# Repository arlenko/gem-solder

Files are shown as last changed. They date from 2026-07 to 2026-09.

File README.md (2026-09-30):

# 💎 Gem Solder

## Overview

Gem Solder is an STM32-powered soldering iron controller for general-purpose C245 tips.
It runs from a PD-compatible USB-C power source or from a DC power source of up to 24V,
including 3S–6S battery packs. USB-C power delivery negotiates up to 20V.

The user interface features a 128×32 OLED display and two buttons. An RGB
status LED gives visual feedback on the current operating mode.

The firmware is a fork of [IronOS](https://github.com/Ralim/IronOS). It ships with the IronOS feature set including a UI available in 35 languages.

The firmware measures the heater resistance of the fitted tip to compute how much power it can handle — up to 140W from DC and up to 100W over USB-C.
The delivered power therefore stays accurate across tips from different manufacturers.

Handle connector built into the 3D-printed housing. The housing carries the connector body, and a
matching PCB piece drops into it, so the pins and wires are soldered to that piece instead of a
special-purpose handle connector having to be sourced.

**Check out the [releases page](https://github.com/arlenko/gem-solder/releases)!**

The ZIP file shipped with a release contains everything needed to build, including a
[bill of materials](BOM/Gem%20Solder%20BOM.xlsx) for sourcing components and cost estimation,
an [interactive BOM](BOM/ibom.html) for convenient PCB assembly by hand, compiled
[bootloader](https://github.com/arlenko/IronOS-dfu) and firmware binaries, and STL files for
3D printing the enclosure.

**Get help and share your ideas on the [discussions](https://github.com/arlenko/gem-solder/discussions) page!**

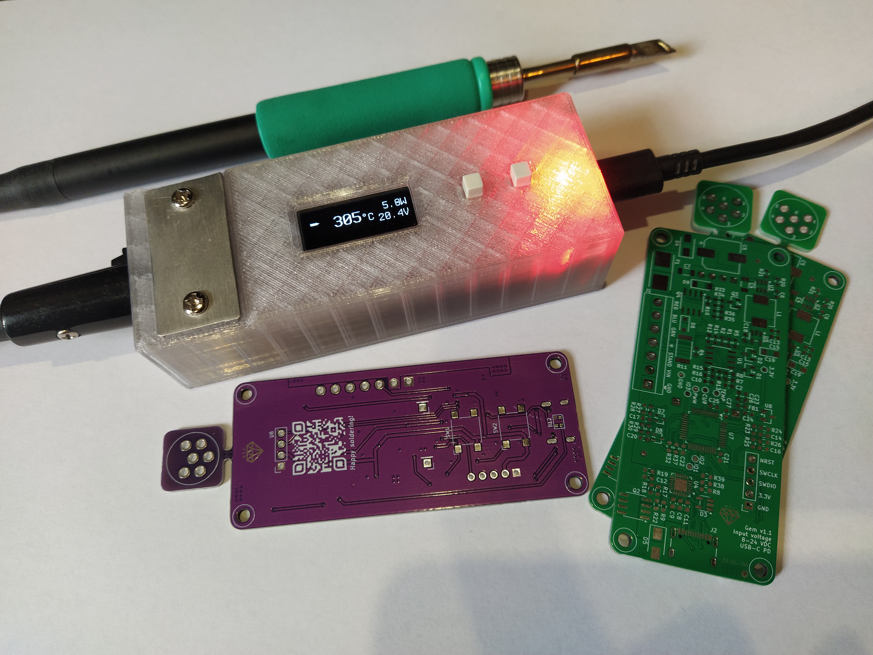
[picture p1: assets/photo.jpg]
Gem Solder


## Table of contents

- [Overview](#overview)
- [Features](#features)
- [Schematic](#schematic)
- [Hardware](#hardware)
- [Enclosure](#enclosure)
- [Firmware flashing](#firmware-flashing)
- [User interface](#user-interface)
- [Power supply recommendations](#power-supply-recommendations)
- [License](#license)

## Features

- Compact, DIY-friendly, two-layer 80×34 mm PCB.
- Current sensing feature measures the heater element's resistance to derive an
  accurate power estimate, so the iron works correctly with aftermarket tips whose resistance differs
  from the 2.4Ω of a genuine C245 tip.
- Resting the metal ring of the handle on a metal plate pulls the stand-sense input
  low and drops the iron to the sleep temperature, slowing tip oxidation. A quick
  tap on the plate toggles sleep when _Tap to sleep_ is enabled in the settings menu.
- An adjustable timeout setting returns the iron to the home screen and
  lets the tip cool down if it stays in sleep mode for too long.
- RGB status LED colour by mode:
  - 🟩 green - standby
  - 🟥 red pulse - heating
  - 🟥 red static - at setpoint
  - 🟦 cyan pulse - cooling, still hot
  - 🟪 violet - sleeping
- Once the DFU bootloader has been flashed to the device, all later firmware
  updates can be done over a USB data cable.
- PID temperature control, adjustable power limit, power pulse to keep power banks
  awake and more from IronOS.
- PD debug menu to read the power source capabilities.
- USB-C PD and an XT60 connector make it workable from a power bank or battery pack, for soldering away from the workbench.
- 20 kHz heater PWM keeps the switching noise of the high-current drive above the audible range.

## Schematic

Gem Solder schematic

## Hardware

Gem Solder PCB was designed in [KiCad](https://www.kicad.org/). It's a two-layer board
with a breakaway panel for a handle connector.

The heart of the device is the STM32F103C8T6 — an ARM Cortex-M3 MCU with 20 KB RAM and
64 KB flash. The STUSB4500QTR is a standalone PD sink controller, responsible for PD
negotiation and VBUS management. It communicates with the MCU via I²C.

The AD8629ARZ is a high-precision, zero-drift operational amplifier that amplifies the
microvolt-level signal from the tip thermocouple.

The tip heater power stage consists of a P-channel MOSFET and a discrete push-pull driver
with a zener diode for maintaining the gate voltage at a safe operating level.

The AP63300WU-7 buck converter provides 4.6 V for biasing the WS2812 RGB LED, then a 3.3 V LDO
regulator steps that down to supply the MCU, the OLED, the op-amp, and the
ambient temperature sensor.

A 5 mΩ current sense resistor enables current measurement for accurate PWM duty
calculation and tip presence detection.

Here's a photo of the assembled and bare PCBs:
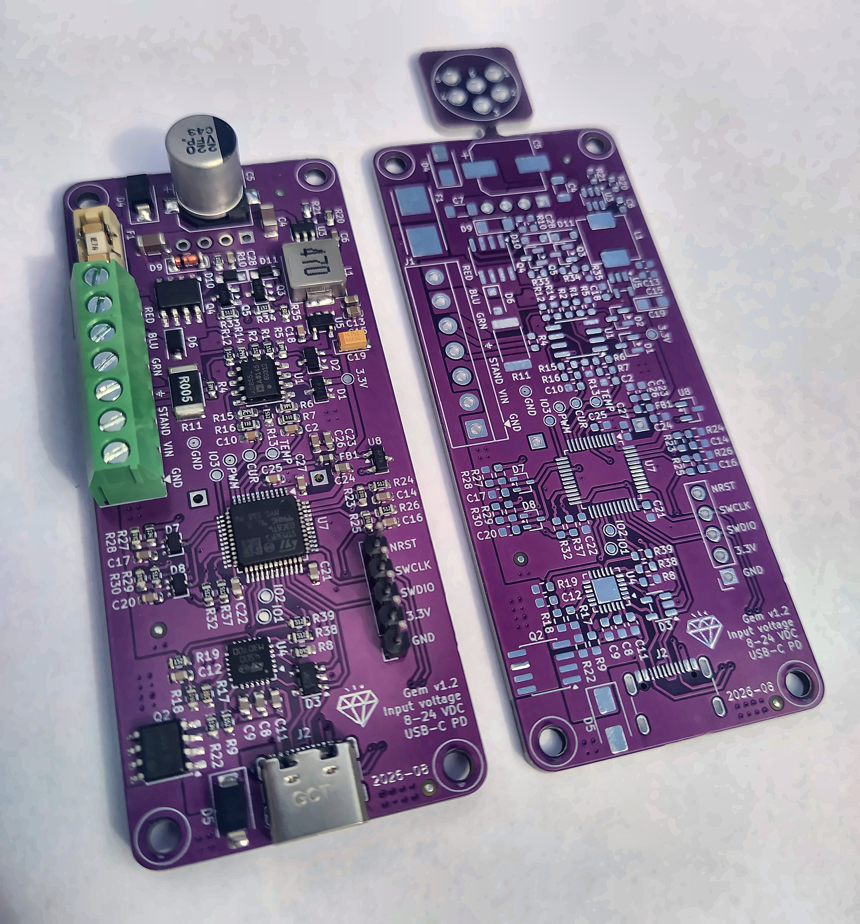
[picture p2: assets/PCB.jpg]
PCB


## Enclosure

Print the enclosure in a semi-transparent material to keep the status LED visible.

The 3D-printed enclosure has a built-in handle connector. Insert the connector PCB piece and
plug in the handle before soldering the pins and wires.

The image below shows how the connector needs to be wired to the screw terminal:

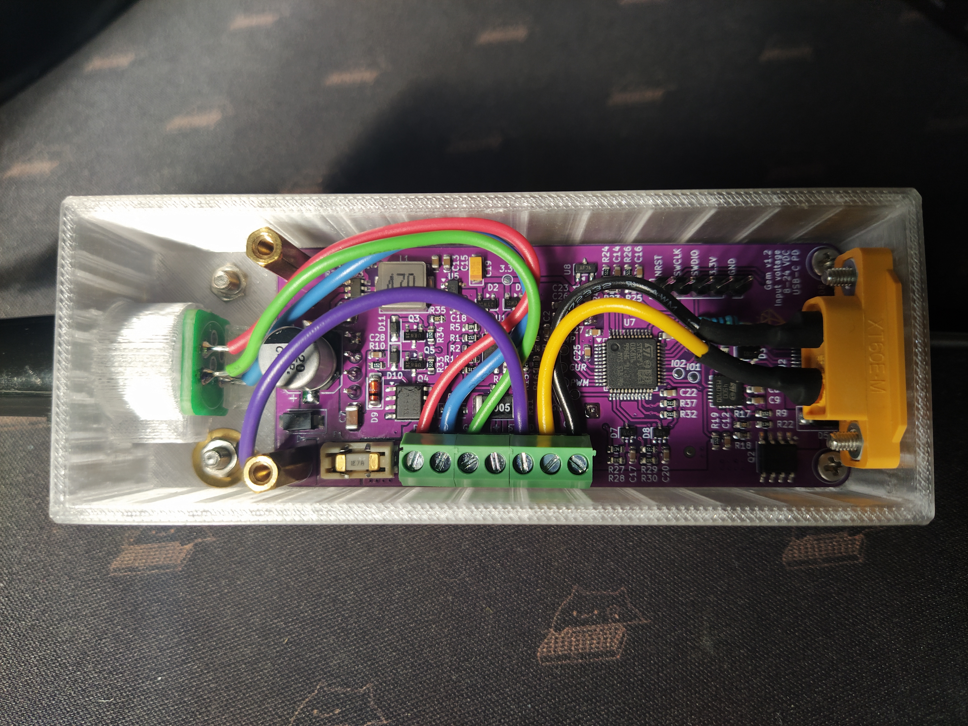
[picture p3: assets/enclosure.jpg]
Enclosure


## Firmware flashing

The STM32F103 has no built-in USB bootloader, so the first flash needs an SWD programmer such
as ST-LINK or DAPLink, wired to the 5-pin SWD header on the board.

Once the DFU bootloader has been flashed, all later updates run over a USB data cable using
[dfu-util](https://dfu-util.sourceforge.net/).

### Flashing via SWD

The flashing instructions depend on the tool and software being used. A genuine ST-LINK can
be used with STM32CubeIDE. DAPLink can be used with the OpenOCD CLI utility:

```sh
sudo openocd -f interface/cmsis-dap.cfg -c "adapter usb vid_pid 0x1a86 0x8012" \
          -f target/stm32f1x.cfg \
          -c "program Firmware/Gem_EN.hex verify reset exit"
```

### Flashing via USB

Once the DFU bootloader has been flashed to the device using SWD, firmware can be flashed
over a USB cable. To enter the DFU bootloader, click and hold button A and connect the USB
cable. The IronOS splash logo should appear on the display, followed by a message reading
"DFU bootloader". Then use dfu-util to upload the firmware:

```sh
sudo dfu-util -a 0 -D Firmware/Gem_EN.dfu -R
```

## User interface

Two buttons control the device:

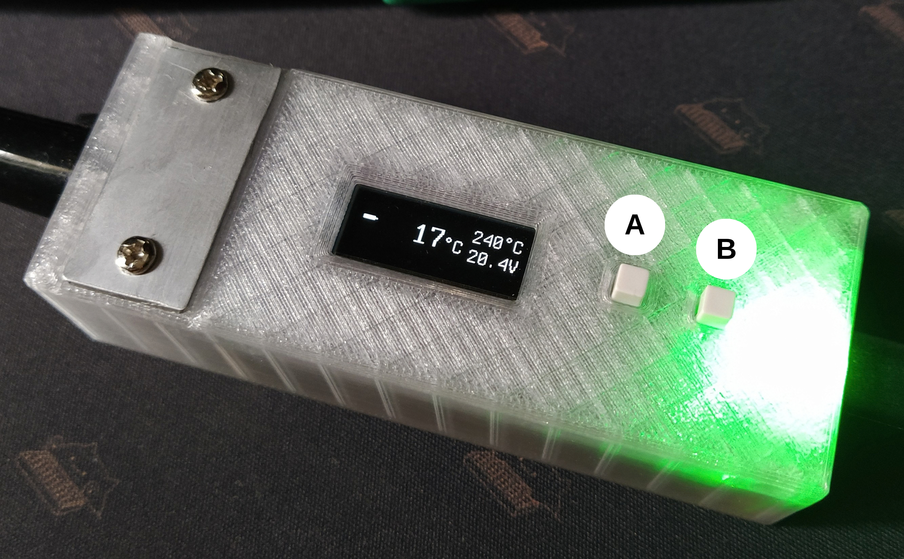
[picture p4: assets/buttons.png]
Buttons


Their functions are as follows:

- **On device power-up:** click and hold button A to enter the DFU bootloader if that was
  flashed to the device. Click and hold button B to enter factory bootloader mode.
- **On the home screen:** click button A to enter soldering mode. Click button B to enter
  device settings. Click and hold button A to adjust the set temperature. Click and hold
  button B to enter the debug menu.
- **In the settings menu:** use button B to scroll and button A to select.
- **In the debug menu:** use button A to scroll and button B to exit. Click and hold button B
  while in the debug menu to enter the PD debug menu.
- **In soldering mode:** click either button to adjust the temperature. Click and hold button B
  to exit to the home screen.

## Power supply recommendations

If an SMPS DC power supply is chosen as a power source, a **SELV power supply with a floating
output is required**. Do not use power supply units whose DC output is connected to mains earth.
Due to how the C245 tips are internally constructed, they provide a low-impedance path between
the RED terminal, to which positive voltage is applied, and the GREEN terminal, which is
connected to mains earth. While the Gem Solder's high-impedance path between the tip body and
the earth terminal should not cause a short circuit, PELV power supplies are not recommended
anyway.

⚠️ **Do not connect USB-C and DC power sources simultaneously!** USB and DC power paths are
internally joined on the board, so one power source ends up connected straight to another.

## License

Gem Solder PCB and enclosure designs are licensed under [CERN Open Hardware Licence Version 2](LICENSE-CERN-OHL-S).
Firmware code is covered by the [GNU General Public License v3.0](LICENSE-GPL-3.0) license unless noted elsewhere.

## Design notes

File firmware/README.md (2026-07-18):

# Gem Firmware
This firmware is derived from [IronOS](https://github.com/Ralim/IronOS)
(v2.23 commit [543fcd0](https://github.com/Ralim/IronOS/commit/543fcd0be6f28daac2f69c1caa4cce1047e1be24)),
originally targeting the Miniware TS101. Due to significant hardware differences between the TS101 and Gem maintaining a separate copy became necessary. Upstream IronOS changes are not automatically merged; this fork is maintained independently.

## Hardware

- **MCU**: STM32F103C8T6 (Cortex-M3, 64K flash, 20K RAM)
- **Display**: 128x32 OLED. SSD1306 display driver
- **Power**: DC and USB-C PD. STUSB4500 PD controller

## Building

1. Enter the source directory:
```
cd source
```

2. Create a Python virtual environment:
```
python -m venv ironos-venv
```

3. Activate virtual environment:
```
source ./ironos-venv/bin/activate # or activate.fish for the fish shell
```

4. Install dependencies:
```
pip install bdflib pyyaml
```

5. Build the firmware:
```
make -j$(nproc)
```
If you need SWD enabled for debugging:
```
make -j$(nproc) swd_enable=1
```

For all subsequent builds in a new terminal session consider activating a Python virtual environment before building the firmware.

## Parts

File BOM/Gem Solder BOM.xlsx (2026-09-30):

Reference | Qty | Value | Footprint | Description | LCSC Part Number | MPN | Link | Price per single unit | Price per Qty
C2,C10,C18 | 3 | 1n | Capacitor_SMD:C_0603_1608Metric | Unpolarized capacitor, small symbol | C163508 | C0603C102J3GACAUTO | C163508 (https://www.lcsc.com/product-detail/) | $0.0127 | $0.0381
C4,C7 | 2 | 10u | Capacitor_SMD:C_1206_3216Metric | Unpolarized capacitor, small symbol | C105175 | MSASU31LBB5106KTNA01 | C105175 (https://www.lcsc.com/product-detail/) | $0.4207 | $0.8414
C5 | 1 | 220u | Capacitor_SMD:CP_Elec_8x10.5 | Polarized capacitor | C278406 | EEEFP1V221AP | C278406 (https://www.lcsc.com/product-detail/) | $0.4923 | $0.4923
C6,C12,C14,C16,C17,C20,C25,C26,C27,C28 | 10 | 100n | Capacitor_SMD:C_0603_1608Metric | Unpolarized capacitor, small symbol | C346190 | CL10B104KA8WPNC | C346190 (https://www.lcsc.com/product-detail/) | $0.0278 | $0.2780
C8,C9,C11,C21,C22,C23,C24 | 7 | 1u | Capacitor_SMD:C_0603_1608Metric | Unpolarized capacitor, small symbol | C85862 | GCM188R71E105KA64D | C85862 (https://www.lcsc.com/product-detail/) | $0.0893 | $0.6251
C13,C15 | 2 | 22u | Capacitor_SMD:C_0603_1608Metric | Unpolarized capacitor, small symbol | C2762594 | CL10A226MO7JZNC | C2762594 (https://www.lcsc.com/product-detail/) | $0.1292 | $0.2584
C19 | 1 | 4.7u 10V | Capacitor_Tantalum_SMD:CP_EIA-3216-18_Kemet-A | Polarized capacitor, small symbol | C7187 | TAJA475K016RNJ | C7187 (https://www.lcsc.com/product-detail/) | $0.2206 | $0.2206
D1,D2 | 2 | BAV199.215 | Package_TO_SOT_SMD:SOT-23 | BAV99 High-speed switching diodes, SOT-23 | C40919 | BAV199.215 | C40919 (https://www.lcsc.com/product-detail/) | $0.0660 | $0.1320
D3 | 1 | ESDA6V1SC5 | Package_TO_SOT_SMD:SOT-23-5 | Quad TVS Diode Array, 6.1V Standoff, 4 Channels, 400W, ±30kV, SOT-23-5 | C2935146 | ESDA6V1SC5 | C2935146 (https://www.lcsc.com/product-detail/) | $0.2890 | $0.2890
D4,D5 | 2 | SMAJ24CA | Diode_SMD:D_SMA |  | C148223 | SMAJ24CA | C148223 (https://www.lcsc.com/product-detail/) | $0.1069 | $0.2138
D6 | 1 | PMEG6010CEH.115 | Diode_SMD:D_SOD-123F | Schottky diode, small symbol | C53113897 | PMEG6010CEH.115-JSM | C53113897 (https://www.lcsc.com/product-detail/) | $0.0469 | $0.0469
D7,D8 | 2 | BAT54SW | Package_TO_SOT_SMD:SOT-323_SC-70 | Vr 30V, If 200mA, Dual schottky barrier diode, in series, SOT-323 | C78606 | BAT54SW.115 | C78606 (https://www.lcsc.com/product-detail/) | $0.0535 | $0.1070
D9 | 1 | BZV55-B12.115 | Diode_SMD:D_MiniMELF | Zener diode, small symbol | C426807 | BZV55-B12.115 | C426807 (https://www.lcsc.com/product-detail/) | $0.0979 | $0.0979
D10,D11 | 2 | 1N4148WSF-7 | Diode_SMD:D_SOD-323_HandSoldering |  | C119617 | 1N4148WSF-7 | C119617 (https://www.lcsc.com/product-detail/) | $0.6677 | $1.3354
D12 | 1 | WS2812B-2020 | Footprints:RGB_LED_WS2812B-2020_2.0x2.0mm |  | C52917434 | WS2812B-2020-V6 | C52917434 (https://www.lcsc.com/product-detail/) | $0.0916 | $0.0916
F1 | 1 | 7A | Footprints:0154100DR | Fuse | C206918 | 0154007.DR | C206918 (https://www.lcsc.com/product-detail/) | $1.9183 | $1.9183
FB1 | 1 | BLM18AG331SN1D | Inductor_SMD:L_0603_1608Metric | Ferrite bead, small symbol | C113010 | BLM18AG331SN1D | C113010 (https://www.lcsc.com/product-detail/) | $0.0139 | $0.0139
J2 | 1 | USB4105-GF-A-060 | Connector_USB:USB_C_Receptacle_GCT_USB4105-xx-A_16P_TopMnt_Horizontal | USB 2.0-only 16P Type-C Receptacle connector | C3025063 | USB4105-GF-A-060 | C3025063 (https://www.lcsc.com/product-detail/) | $1.1952 | $1.1952
J3,J4 | 2 | Conn_01x01_Pin | Connector_PinHeader_2.54mm:PinHeader_1x01_P2.54mm_Vertical | Generic connector, single row, 01x01, script generated | C7501259 | ZX-PZ2.54-1-1PZZ | C7501259 (https://www.lcsc.com/product-detail/) | $0.0146 | $0.0292
J5 | 1 | Conn_01x05_Socket | Connector_PinSocket_2.54mm:PinSocket_1x05_P2.54mm_Vertical | Generic connector, single row, 01x05, script generated | C7171947 | 215298-5 | C7171947 (https://www.lcsc.com/product-detail/) | $0.8446 | $0.8446
L1 | 1 | 47uH | Inductor_SMD:L_APV_APH0630 | Inductor | C706600 | SMMS0630-470MT | C706600 (https://www.lcsc.com/product-detail/) | $0.1268 | $0.1268
Q2,Q4 | 2 | AOSP21321 | Package_SO:SOIC-8_3.9x4.9mm_P1.27mm | -6.7A Id, -20V Vds, P-Channel HEXFET Power MOSFET, SO-8 | C560863 | AOSP21321 | C560863 (https://www.lcsc.com/product-detail/) | $0.2159 | $0.4318
Q3,Q5 | 2 | BSR14 | Package_TO_SOT_SMD:SOT-23 | TRANS NPN 40V 800mA SOT-23 | C258201 | BSR14 | C258201 (https://www.lcsc.com/product-detail/) | $0.2776 | $0.5552
R1,R2,R9,R10,R19,R31,R34 | 7 | 1.5k | Resistor_SMD:R_0603_1608Metric | Resistor, small symbol | C2930050 | FRC0603F1501TS | C2930050 (https://www.lcsc.com/product-detail/) | $0.0027 | $0.0189
R4 | 1 | 1M | Resistor_SMD:R_0603_1608Metric | Resistor, small symbol | C2907003 | FRC0603F1004TS | C2907003 (https://www.lcsc.com/product-detail/) | $0.0027 | $0.0027
R5,R6 | 2 | 390k | Resistor_SMD:R_0603_1608Metric | Resistor, small symbol | C2907158 | FRC0603J394 TS | C2907158 (https://www.lcsc.com/product-detail/) | $0.0022 | $0.0044
R7,R16 | 2 | 10R | Resistor_SMD:R_0603_1608Metric | Resistor, small symbol | C2907091 | FRC0603J100 TS | C2907091 (https://www.lcsc.com/product-detail/) | $0.0027 | $0.0054
R8,R28,R30 | 3 | 10k | Resistor_SMD:R_0603_1608Metric | Resistor, small symbol | C4134045 | RCS060310K0JNEA | C4134045 (https://www.lcsc.com/product-detail/) | $0.0476 | $0.1428
R17,R20,R35 | 3 | 20k | Resistor_SMD:R_0603_1608Metric | Resistor, small symbol | C2907011 | FRC0603F2002TS | C2907011 (https://www.lcsc.com/product-detail/) | $0.0027 | $0.0081
R11 | 1 | RMF2512FTR005 | Resistor_SMD:R_2512_6332Metric | Resistor, small symbol | C48533600 | FRM253WJR005TM | C48533600 (https://www.lcsc.com/product-detail/) | $0.0335 | $0.0335
R12,R13,R24,R26,R29,R32,R37,R38,R39 | 9 | 5k1 | Resistor_SMD:R_0603_1608Metric | Resistor, small symbol | C2907044 | FRC0603F5101TS | C2907044 (https://www.lcsc.com/product-detail/) | $0.0028 | $0.0252
R14,R15 | 2 | 240k | Resistor_SMD:R_0603_1608Metric | Resistor, small symbol | C2930036 | FRC0603J244TS | C2930036 (https://www.lcsc.com/product-detail/) | $0.0023 | $0.0046
R18,R23,R25 | 3 | 100R | Resistor_SMD:R_0603_1608Metric | Resistor, small symbol | C2076611 | CRCW0603100RJNEAC | C2076611 (https://www.lcsc.com/product-detail/) | $0.0156 | $0.0468
R20,R22,R27 | 3 | 130k | Resistor_SMD:R_0603_1608Metric | Resistor, small symbol | C2907099 | FRC0603J134 TS | C2907099 (https://www.lcsc.com/product-detail/) | $0.0024 | $0.0072
R21 | 1 | 27k | Resistor_SMD:R_0603_1608Metric | Resistor, small symbol | C2930084 | FRC0603F2702TS | C2930084 (https://www.lcsc.com/product-detail/) | $0.0028 | $0.0028
SW1,SW2 | 2 | SW_Omron_B3FS | Button_Switch_SMD:SW_SPST_Omron_B3FS-100xP | Omron B3FS 6x6mm single pole normally-open tactile switch | C5594007 | B3FS-1050 | C5594007 (https://www.lcsc.com/product-detail/) | $1.2121 | $2.4242
U1 | 1 | AD8629ARZ | Package_SO:SOIC-8_3.9x4.9mm_P1.27mm | Dual Precision, Very Low Noise, Low Input Bias Current, Wide Bandwidth JFET Operational Amplifiers, SOIC-8 | C23487 | AD8629ARZ-REEL7 | C23487 (https://www.lcsc.com/product-detail/) | $4.9347 | $4.9347
U3 | 1 | AP63300WU-7 | Package_TO_SOT_SMD:TSOT-23-6 | 2A, 500kHz Buck DC/DC Converter, adjustable output voltage, TSOT-23-6 | C2158012 | AP63300WU-7 | C2158012 (https://www.lcsc.com/product-detail/) | $0.6580 | $0.6580
U4 | 1 | STUSB4500QTR | Footprints:QFN-24-1EP_4x4mm_P0.5mm_EP2.65x2.65mm | Stand-alone USB PD controller (with sink Auto-run mode), QFN-24 | C2678061 | STUSB4500QTR | C2678061 (https://www.lcsc.com/product-detail/) | $2.1956 | $2.1956
U5 | 1 | MIC5219-3.3YM5 | Package_TO_SOT_SMD:SOT-23-5 | 500mA low dropout linear regulator, fixed 3.3V output, SOT-23-5 | C29613 | MIC5219-3.3YM5-TR | C29613 (https://www.lcsc.com/product-detail/) | $0.5892 | $0.5892
U6 | 1 | OLED0.91_128x32_I2C | Footprints:OLED_128x32_0.91 | 0.91 128x32 SSD1306 chip I2C LCD, OLED, Graphic RoHS | C5248081 | HS91L02W2C01 | C5248081 (https://www.lcsc.com/product-detail/) | $2.2378 | $2.2378
U7 | 1 | STM32F103C8T6 | Package_QFP:LQFP-48_7x7mm_P0.5mm | STMicroelectronics Arm Cortex-M3 MCU, 64KB flash, 20KB RAM, 72 MHz, 2.0-3.6V, 37 GPIO, LQFP48 | C8734 | STM32F103C8T6 | C8734 (https://www.lcsc.com/product-detail/) | $2.0073 | $2.0073
U8 | 1 | MCP9700AT-ETT | Package_TO_SOT_SMD:SOT-23 | Low power, analog thermistor temperature sensor, ±2C accuracy, -40C to +125C, in SOT-23-3 | C127949 | MCP9700AT-E/TT | C127949 (https://www.lcsc.com/product-detail/) | $0.4460 | $0.4460
 |  |  |  |  |  |  |  | Total for PCB components | $25.9777
PCB | 1 |  |  |  |  |  |  | $2.0000 | $2.0000
Stencil | 1 |  |  |  |  |  |  | $7.0000 | $7.0000
 |  |  |  |  |  |  |  | Total for PCB fabrication | $9.00
XT60E-M connector | 1 |  |  |  | C3040679 | XT60E-M.G.Y | C3040679 (https://www.lcsc.com/product-detail/) | $0.6084 | $0.6084
Screw terminal (2 pin) | 2 | DEGSON DG350-3.5-02P-14-00A(H) |  |  | C2760668 |  | C2760668 (https://www.lcsc.com/product-detail/) | $0.1706 | $0.3412
Screw terminal (3 pin) | 1 | DEGSON DG350-3.5-03P-14-00A(H) |  |  | C2760669 |  | C2760669 (https://www.lcsc.com/product-detail/) | $0.1899 | $0.1899
Handle connector pins | 5 |  |  |  | C17283940 | 1460-9-00-80-00-00-03-0 | C17283940 (https://www.lcsc.com/product-detail/) | $0.3633 | $1.8165
Screws M2.5x6 | 4 |  |  | For sequring PCB and XT60 connector
Screws M2.5x10 | 4 |  |  | For sequring enclosure lid and standby sense plate
Nuts M2.5 | 2 |  |  | For sequring standby sense plate
PCB standoffs L=16 | 2 |  |  | For sequring PCB and enclosure lid
Threaded inserts for plastic M2.5 | 4
Ring terminal M2.5 | 1 |  |  | For connecting standby sense wire to sense plate
Button cups | 2 | B32-1060 |  |  | C2733560 | B32-1060 | C2733560 (https://www.lcsc.com/product-detail/) | $0.1032 | $0.2064
Enclosure 3D print | 1 |  |  |  |  |  |  | $5.0000 | $5.0000
 |  |  |  |  |  |  |  | Total for others | $8.16
T245 handle | 1 |  |  |  |  |  |  | $15.0000 | $15.0000
C245 tip | 1 |  |  |  |  |  |  | $5.0000 | $5.0000
 |  |  |  |  |  |  |  | Total for handle+tip | $20.00
 |  |  |  |  |  |  |  | Total | $63.14

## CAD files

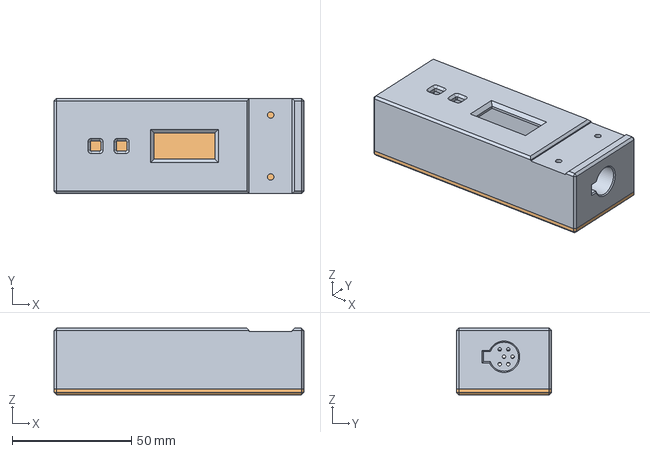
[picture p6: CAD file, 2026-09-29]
enclosure/Gem_Solder_Enclosure.FCStd
105.0 x 40.0 x 28.0 mm
Тіло
Enclosure_Lid

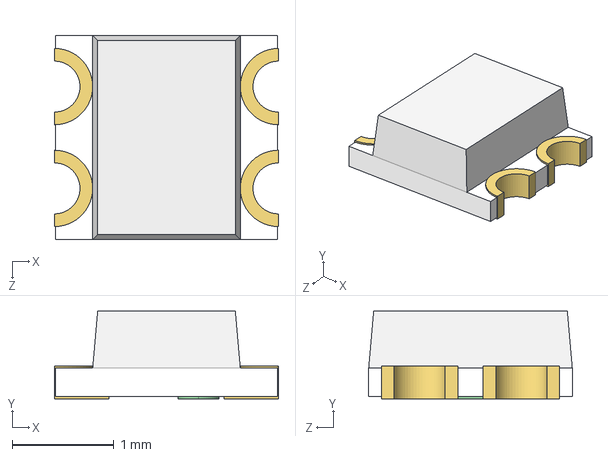
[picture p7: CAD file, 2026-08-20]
hardware/3D-models/WS2812-2020.STEP
2.20 x 0.86 x 2.00 mm

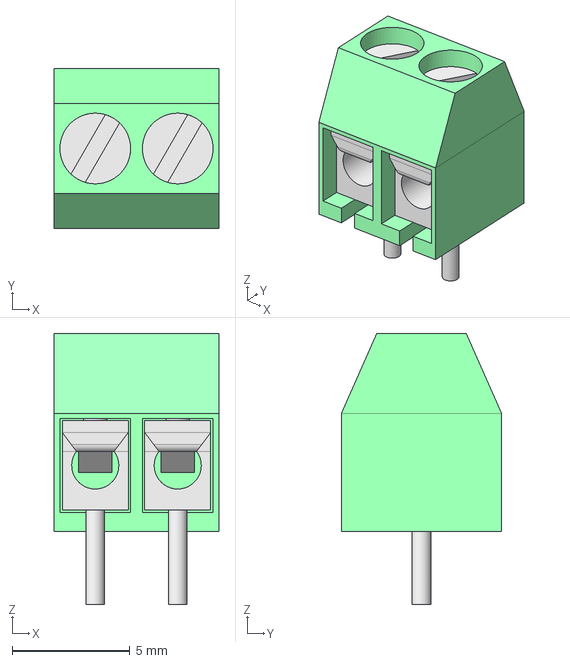
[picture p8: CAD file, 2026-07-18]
hardware/3D-models/DG350-3.5-2P.step
7.00 x 6.80 x 11.5 mm

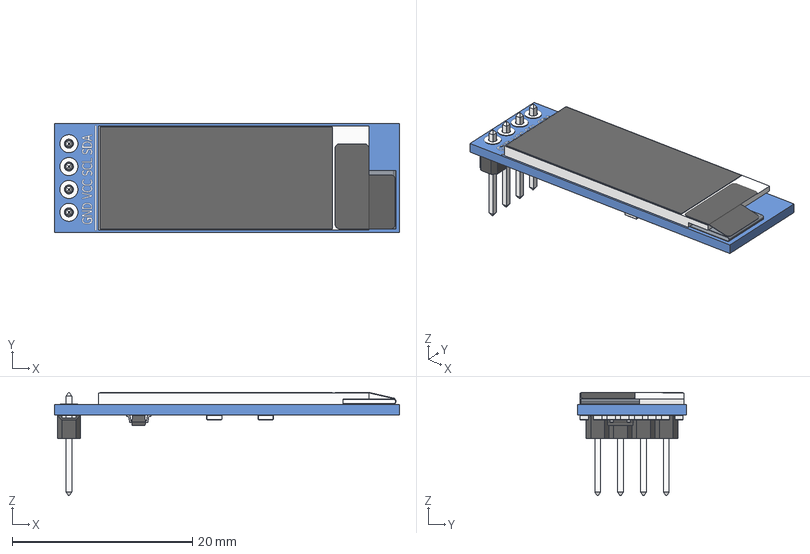
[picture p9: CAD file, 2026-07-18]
hardware/3D-models/OLED_0.91_128x32.stp
38.3 x 12.1 x 11.5 mm
OLED_0.91_128x32
Pin Header 4 x 1 TH 2.54mm Pitch
RESC-0603 x 13
2SD0601A

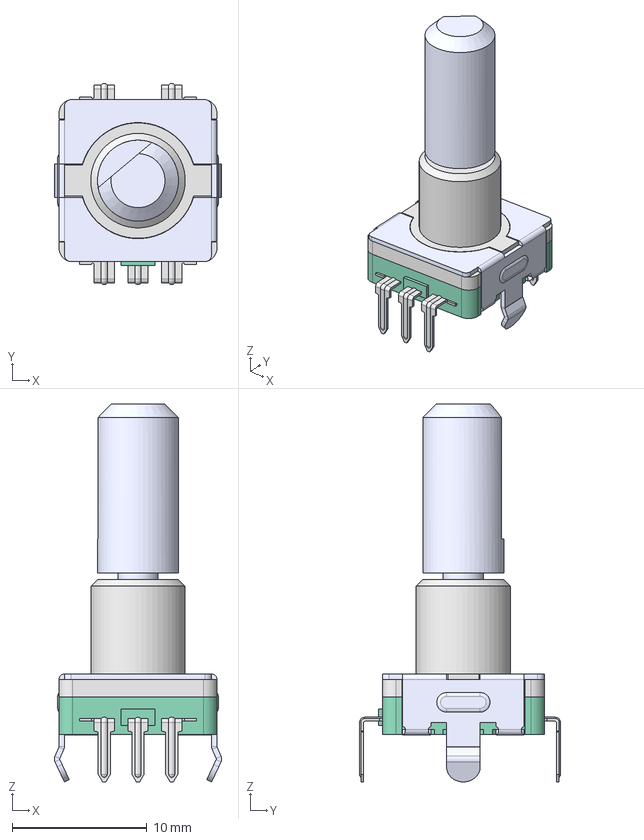
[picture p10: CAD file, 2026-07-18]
hardware/3D-models/EC11-THT-20F-green.step
12.4 x 14.9 x 28.0 mm
Lb7
20F
EC11-Housing-THT

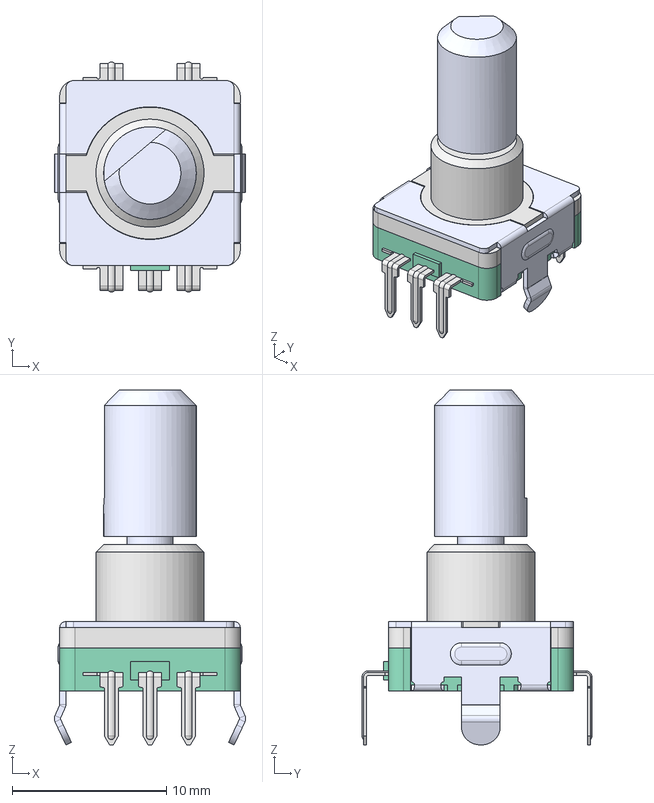
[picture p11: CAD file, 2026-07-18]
hardware/3D-models/EC11-THT-15F-green.step
12.4 x 14.9 x 23.0 mm
Lb5
15F
EC11-Housing-THT

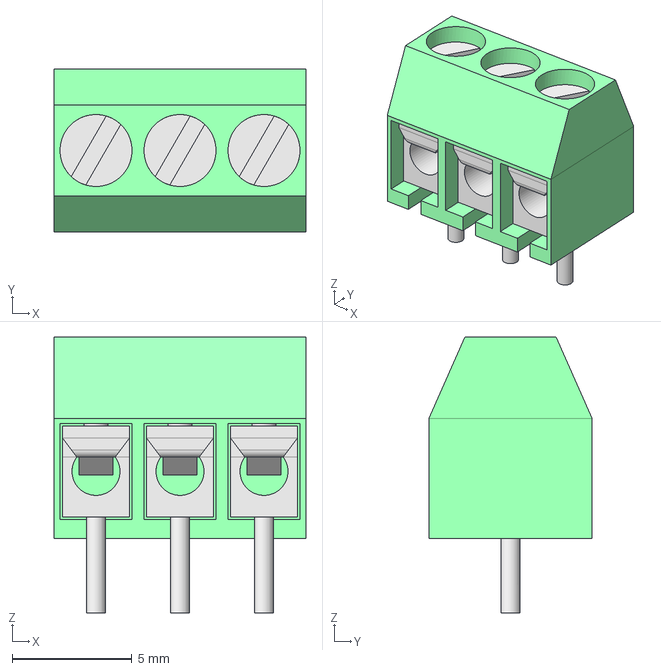
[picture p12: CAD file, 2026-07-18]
hardware/3D-models/DG350-3.5-3P.step
10.5 x 6.80 x 11.5 mm

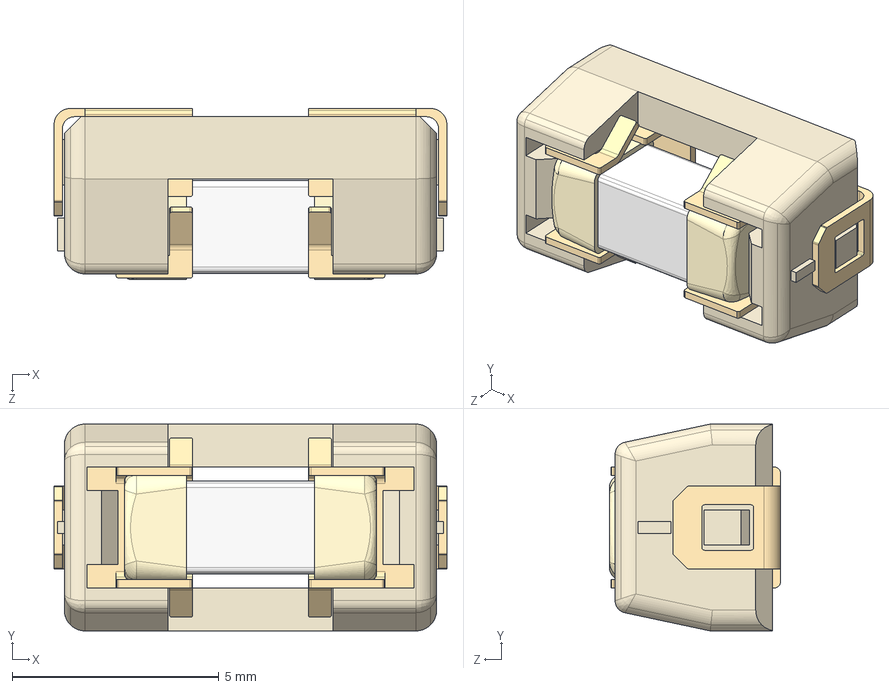
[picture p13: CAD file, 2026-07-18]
hardware/3D-models/0154007.DRTL.stp
9.50 x 5.00 x 4.14 mm
0679H1000-xxsingle fonts v2.step
Plastic holder-0.step
Terminal.step

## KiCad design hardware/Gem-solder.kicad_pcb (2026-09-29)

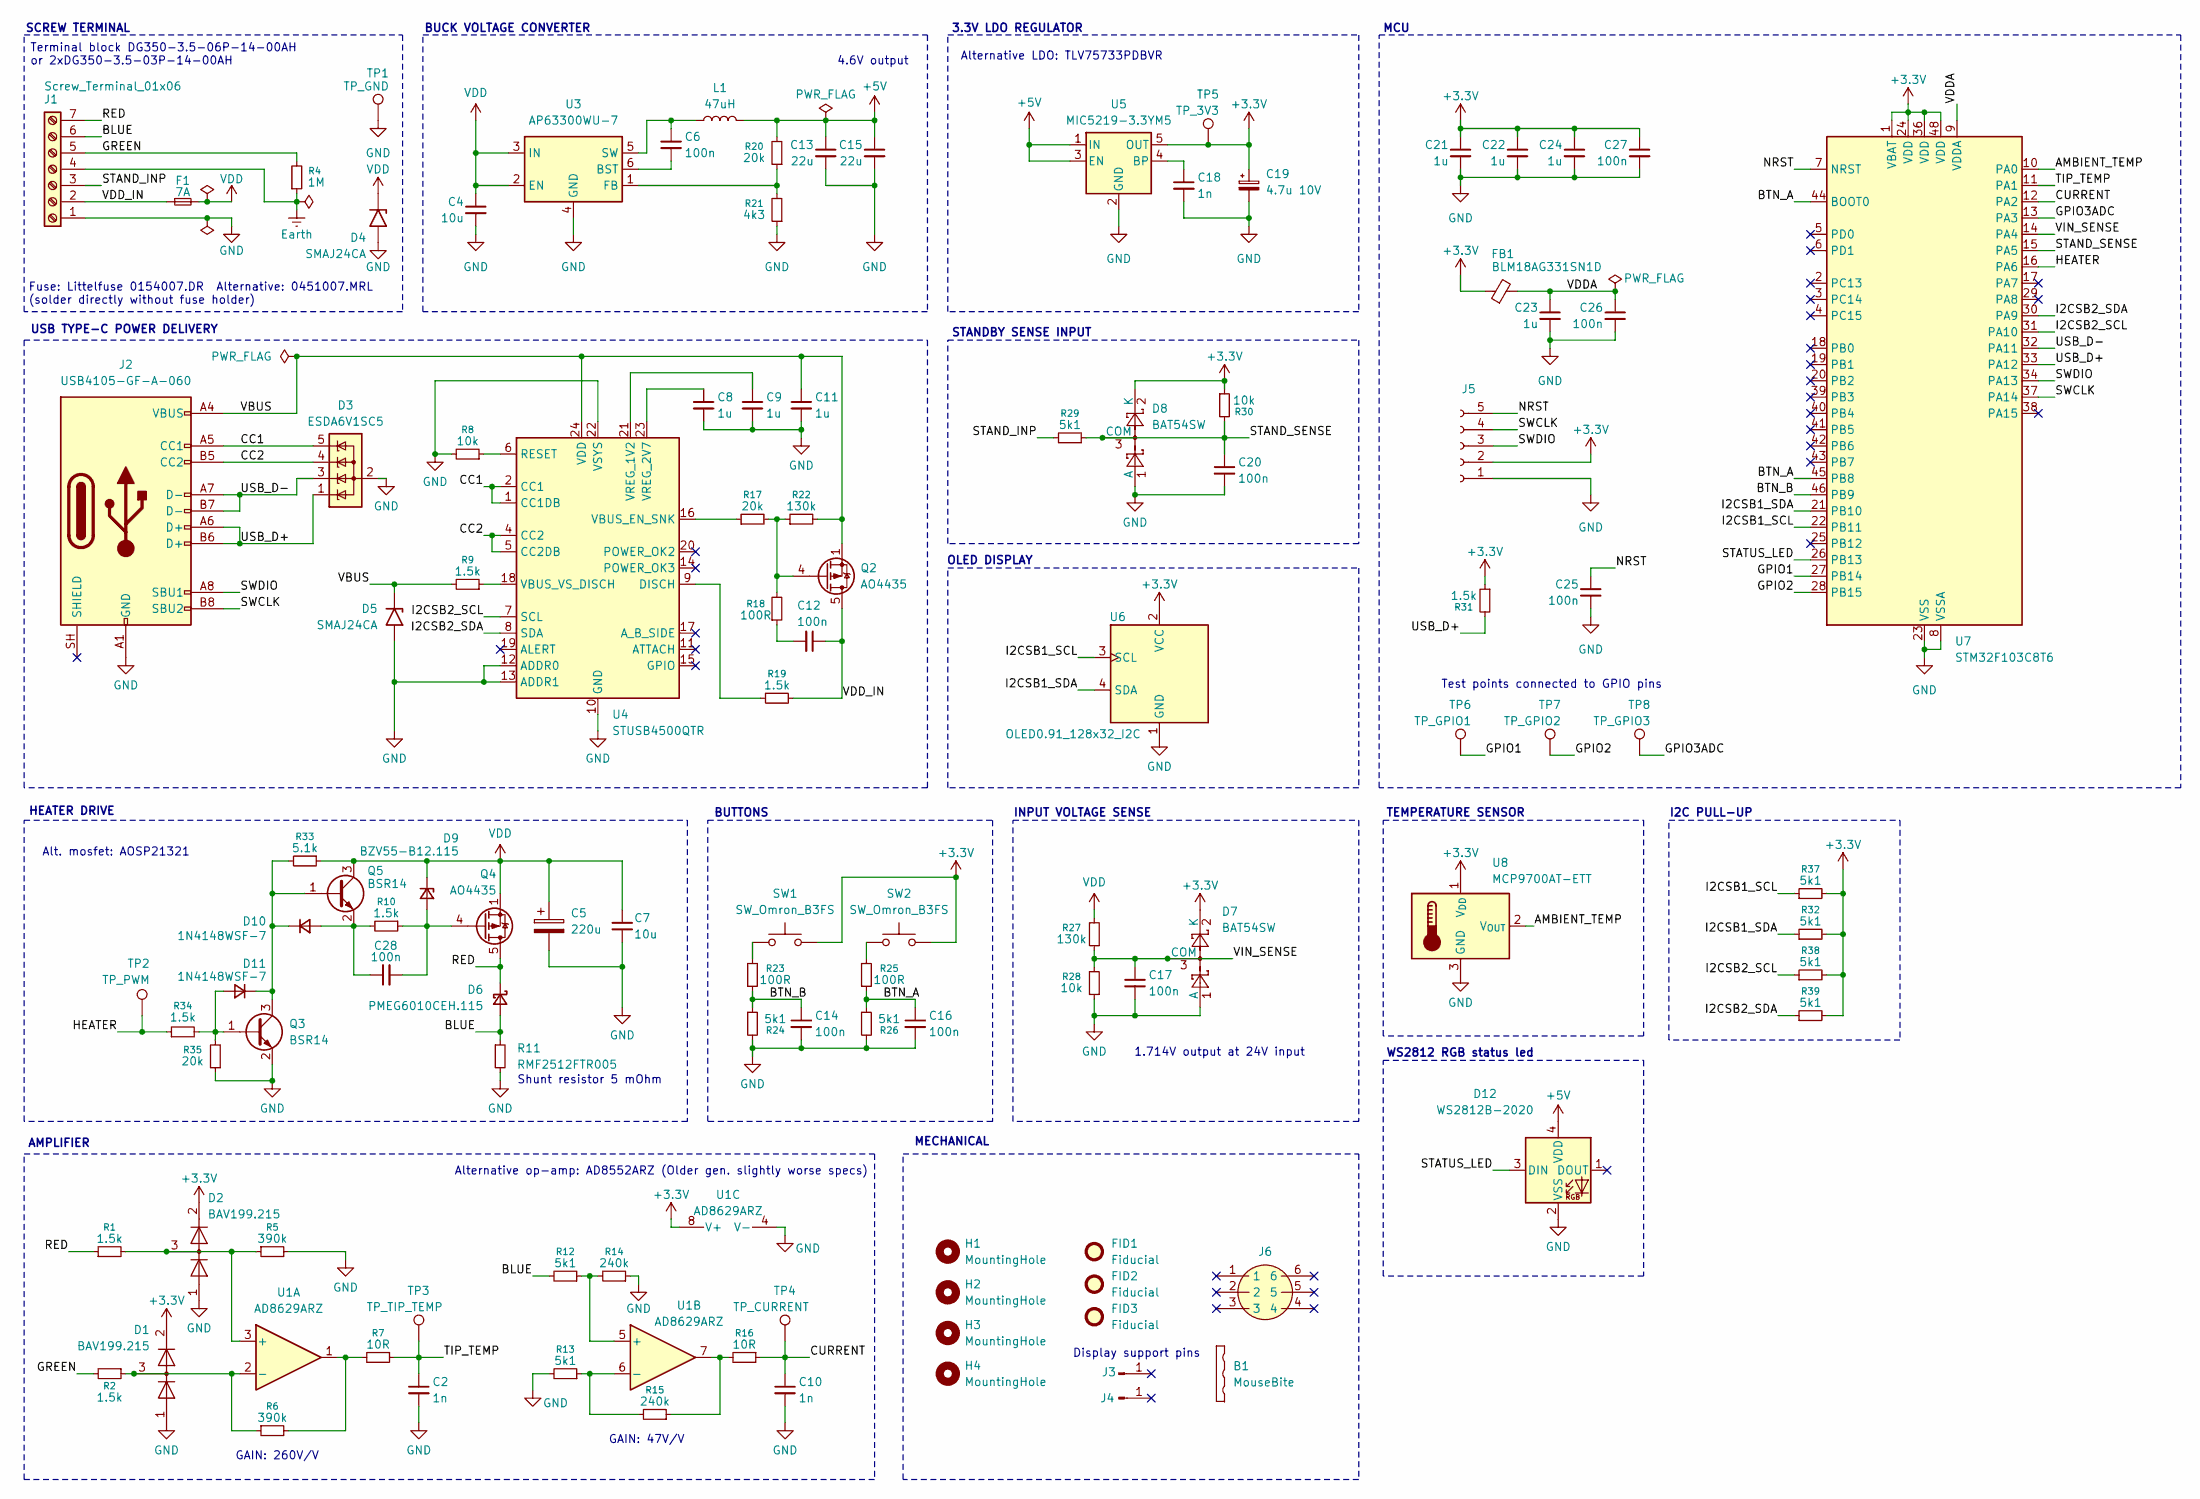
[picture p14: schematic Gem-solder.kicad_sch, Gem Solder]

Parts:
B1: MouseBite; MouseBite-Slot_2.0x2.0mm_outset_D0.5mm_P0.85mm_3h
C2, C10, C18: 1n; C_0603_1608Metric; MPN C0603C102J3GACAUTO; LCSC Part Number C163508
C4, C7: 10u; C_1206_3216Metric; MPN MSASU31LBB5106KTNA01; LCSC Part Number C105175
C5: 220u; CP_Elec_8x10.5; MPN EEEFP1V221AP; LCSC Part Number C278406
C6, C12, C14, C16, C17, C20, C25, C26, C27, C28: 100n; C_0603_1608Metric; MPN CL10B104KA8WPNC; LCSC Part Number C346190
C8, C9, C11, C21, C22, C23, C24: 1u; C_0603_1608Metric; MPN GCM188R71E105KA64D; LCSC Part Number C85862
C13, C15: 22u; C_0603_1608Metric; MPN CL10A226MO7JZNC; LCSC Part Number C2762594
C19: 4.7u 10V; CP_EIA-3216-18_Kemet-A; MPN TAJA475K016RNJ; LCSC Part Number C7187
D1, D2: BAV199.215; SOT-23; MPN BAV199.215; LCSC Part Number C40919
D3: ESDA6V1SC5; SOT-23-5; MPN ESDA6V1SC5; LCSC Part Number C2935146
D4, D5: SMAJ24CA; D_SMA; MPN SMAJ24CA; LCSC Part Number C148223
D6: PMEG6010CEH.115; D_SOD-123F; MPN PMEG6010CEH.115-JSM; LCSC Part Number C53113897
D7, D8: BAT54SW; SOT-323_SC-70; MPN BAT54SW.115; LCSC Part Number C78606
D9: BZV55-B12.115; D_MiniMELF; MPN BZV55-B12.115; LCSC Part Number C426807
D10, D11: 1N4148WSF-7; D_SOD-323_HandSoldering; MPN 1N4148WSF-7; LCSC Part Number C119617
D12: WS2812B-2020; RGB_LED_WS2812B-2020_2.0x2.0mm; MPN WS2812B-2020-V6; LCSC Part Number C52917434
F1: 7A; 0154100DR; MPN 0154007.DR; LCSC Part Number C206918
FB1: BLM18AG331SN1D; L_0603_1608Metric; MPN BLM18AG331SN1D; LCSC Part Number C113010
FID1, FID2, FID3: Fiducial; Fiducial_0.75mm_Mask1.5mm
H1, H2, H3, H4: MountingHole; MountingHole_2.7mm_M2.5_DIN965
J1: Screw_Terminal_01x06; TerminalBlock_DG350-3.5-07P-14-00AH_1x07_P3.50mm
J2: USB4105-GF-A-060; USB_C_Receptacle_GCT_USB4105-xx-A_16P_TopMnt_Horizontal; MPN USB4105-GF-A-060; LCSC Part Number C3025063
J3, J4: Conn_01x01_Pin; PinHeader_1x01_P2.54mm_Vertical; MPN ZX-PZ2.54-1-1PZZ; LCSC Part Number C7501259
J5: Conn_01x05_Socket; PinSocket_1x05_P2.54mm_Vertical; MPN 215298-5; LCSC Part Number C7171947
J6: Connector_Hirose_RPC1-12RB-6P(72)
L1: 47uH; L_APV_APH0630; MPN SMMS0630-470MT; LCSC Part Number C706600
Q2, Q4: AO4435; SOIC-8_3.9x4.9mm_P1.27mm; MPN IRF7416TRPBF; LCSC Part Number C3000
Q3, Q5: BSR14; SOT-23; MPN BSR14; LCSC Part Number C258201
R1, R2, R9, R10, R19, R31, R34: 1.5k; R_0603_1608Metric; MPN FRC0603F1501TS; LCSC Part Number C2930050
R4: 1M; R_0603_1608Metric; MPN FRC0603F1004TS; LCSC Part Number C2907003
R5, R6: 390k; R_0603_1608Metric; MPN FRC0603J394 TS; LCSC Part Number C2907158
R7, R16: 10R; R_0603_1608Metric; MPN FRC0603J100 TS; LCSC Part Number C2907091
R8, R28, R30: 10k; R_0603_1608Metric; MPN RCS060310K0JNEA; LCSC Part Number C4134045
R11: RMF2512FTR005; R_2512_6332Metric; MPN FRM253WJR005TM; LCSC Part Number C48533600
R12, R13, R24, R26, R29, R32, R37, R38, R39: 5k1; R_0603_1608Metric; MPN FRC0603F5101TS; LCSC Part Number C2907044
R14, R15: 240k; R_0603_1608Metric; MPN FRC0603J244TS; LCSC Part Number C2930036
R17, R20, R35: 20k; R_0603_1608Metric; MPN FRC0603F2002TS; LCSC Part Number C2907011
R18, R23, R25: 100R; R_0603_1608Metric; MPN CRCW0603100RJNEAC; LCSC Part Number C2076611
R21: 4k3; R_0603_1608Metric; MPN RS-03K4301FT; LCSC Part Number C310281
R22, R27: 130k; R_0603_1608Metric; MPN FRC0603J134 TS; LCSC Part Number C2907099
R33: 5.1k; R_0603_1608Metric; MPN FRC0603F1501TS; LCSC Part Number C2930050
SW1, SW2: SW_Omron_B3FS; SW_SPST_Omron_B3FS-100xP; MPN B3FS-1050; LCSC Part Number C5594007
TP1: TP_GND; TestPoint_Pad_D1.0mm
TP2: TP_PWM; TestPoint_Pad_D1.0mm
TP3: TP_TIP_TEMP; TestPoint_Pad_D1.0mm
TP4: TP_CURRENT; TestPoint_Pad_D1.0mm
TP5: TP_3V3; TestPoint_Pad_D1.0mm
TP6: TP_GPIO1; TestPoint_Pad_D1.0mm
TP7: TP_GPIO2; TestPoint_Pad_D1.0mm
TP8: TP_GPIO3; TestPoint_Pad_D1.0mm
U1: AD8629ARZ; SOIC-8_3.9x4.9mm_P1.27mm; MPN AD8629ARZ-REEL7; LCSC Part Number C23487
U3: AP63300WU-7; TSOT-23-6; MPN AP63300WU-7; LCSC Part Number C2158012
U4: STUSB4500QTR; QFN-24-1EP_4x4mm_P0.5mm_EP2.65x2.65mm; MPN STUSB4500QTR; LCSC Part Number C2678061
U5: MIC5219-3.3YM5; SOT-23-5; MPN MIC5219-3.3YM5-TR; LCSC Part Number C29613
U6: OLED0.91_128x32_I2C; OLED_128x32_0.91; MPN HS91L02W2C01; LCSC Part Number C5248081
U7: STM32F103C8T6; LQFP-48_7x7mm_P0.5mm; MPN STM32F103C8T6; LCSC Part Number C8734
U8: MCP9700AT-ETT; SOT-23; MPN MCP9700AT-E/TT; LCSC Part Number C127949

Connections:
+3.3V: C19.1, C21.1, C22.1, C24.1, C27.1, D1.2 (A), D2.2 (A), D7.2 (K), D8.2 (K), FB1.1, J5.2, R30.1, R31.1, R32.2, R37.2, R38.2, R39.2, SW1.2, SW2.2, TP5.1 (1_1), U1.8 (V+), U5.5 (OUT), U6.2 (VCC), U7.1 (VBAT), U7.24 (VDD), U7.36 (VDD), U7.48 (VDD), U8.1 (V_{DD})
+5V: C13.1, C15.1, D12.4 (VDD), L1.2, R20.2, U5.1 (IN), U5.3 (EN)
/AMBIENT_TEMP: U7.10 (PA0), U8.2 (V_{OUT})
/BLUE: D6.2 (A), J1.6, R11.1, R12.2
/BTN_A: C16.1, R25.1, R26.1, U7.44 (BOOT0), U7.45 (PB8)
/BTN_B: C14.1, R23.1, R24.1, U7.46 (PB9)
/CC1: D3.5 (K), J2.A5 (CC1), U4.1 (CC1DB), U4.2 (CC1)
/CC2: D3.4 (K), J2.B5 (CC2), U4.4 (CC2), U4.5 (CC2DB)
/CURRENT: C10.1, R16.1, TP4.1 (1_1), U7.12 (PA2)
/GPIO1: TP6.1 (1_1), U7.27 (PB14)
/GPIO2: TP7.1 (1_1), U7.28 (PB15)
/GPIO3ADC: TP8.1 (1_1), U7.13 (PA3)
/GREEN: J1.5, R2.2, R4.2
/HEATER: R34.1, TP2.1 (1_1), U7.16 (PA6)
/I2CSB1_SCL: R37.1, U6.3 (SCL), U7.22 (PB11)
/I2CSB1_SDA: R32.1, U6.4 (SDA), U7.21 (PB10)
/I2CSB2_SCL: R38.1, U4.7 (SCL), U7.31 (PA10)
/I2CSB2_SDA: R39.1, U4.8 (SDA), U7.30 (PA9)
/NRST: C25.1, J5.5, U7.7 (NRST)
/RED: D6.1 (K), J1.7, Q4.5 (D), Q4.6 (D), Q4.7 (D), Q4.8 (D), R1.1
/STAND_INP: J1.3, R29.2
/STAND_SENSE: C20.1, D8.3 (COM), R29.1, R30.2, U7.15 (PA5)
/STATUS_LED: D12.3 (DIN), U7.26 (PB13)
/SWCLK: J2.B8 (SBU2), J5.4, U7.37 (PA14)
/SWDIO: J2.A8 (SBU1), J5.3, U7.34 (PA13)
/TIP_TEMP: C2.1, R7.1, TP3.1 (1_1), U7.11 (PA1)
/USB_D+: D3.1 (K), J2.A6 (D+), J2.B6 (D+), R31.2, U7.33 (PA12)
/USB_D-: D3.3 (K), J2.A7 (D-), J2.B7 (D-), U7.32 (PA11)
/VBUS: C11.1, D5.1 (A1), J2.A4 (VBUS), J2.A9 (VBUS), J2.B4 (VBUS), J2.B9 (VBUS), Q2.1 (S), Q2.2 (S), Q2.3 (S), R9.2, R22.2, U4.24 (VDD)
/VDDA: C23.1, C26.1, FB1.2, U7.9 (VDDA)
/VDD_IN: C12.1, F1.1, J1.2, Q2.5 (D), Q2.6 (D), Q2.7 (D), Q2.8 (D), R19.2
/VIN_SENSE: C17.1, D7.3 (COM), R27.1, R28.2, U7.14 (PA4)
Earth: J1.4, R4.1
GND: C2.2, C4.2, C5.2, C7.2, C8.2, C9.2, C10.2, C11.2, C13.2, C14.2, C15.2, C16.2, C17.2, C18.2, C19.2, C20.2, C21.2, C22.2, C23.2, C24.2, C25.2, C26.2, C27.2, D1.1 (K), D2.1 (K), D3.2 (A), D4.2 (A2), D5.2 (A2), D7.1 (A), D8.1 (A), D12.2 (VSS), J1.1, J2.A1 (GND), J2.A12 (GND), J2.B1 (GND), J2.B12 (GND), J5.1, Q3.2 (E), R5.2, R8.2, R11.2, R13.2, R14.1, R21.1, R24.2, R26.2, R28.1, R35.1, TP1.1 (1_1), U1.4 (V-), U3.4 (GND), U4.10 (GND), U4.12 (ADDR0), U4.13 (ADDR1), U4.22 (VSYS), U4.25 (GND), U5.2 (GND), U6.1 (GND), U7.8 (VSSA), U7.23 (VSS), U7.35 (VSS), U7.47 (VSS), U8.3 (GND)
unnamed: C12.2, R18.1
unnamed: C28.2, D9.2 (A), Q4.4 (G), R10.1
unnamed: C28.1, D10.2 (A), Q5.2 (E), R10.2
unnamed: D10.1 (K), D11.1 (K), Q3.3 (C), Q5.1 (B), R33.2
unnamed: D11.2 (A), Q3.1 (B), R34.2, R35.2
unnamed: Q2.4 (G), R17.2, R18.2, R22.1
unnamed: R6.2, R7.2, U1.1
unnamed: R15.1, R16.2, U1.7
unnamed: R23.2, SW1.1
unnamed: R25.2, SW2.1
unnamed: D2.3 (K), R1.2, R5.1, U1.3 (+)
unnamed: D1.3 (K), R2.1, R6.1, U1.2 (-)
unnamed: R12.1, R14.2, U1.5 (+)
unnamed: R13.1, R15.2, U1.6 (-)
unnamed: C6.2, U3.6 (BST)
unnamed: R20.1, R21.2, U3.1 (FB)
unnamed: C6.1, L1.1, U3.5 (SW)
unnamed: R19.1, U4.9 (DISCH)
unnamed: R8.1, U4.6 (RESET)
unnamed: R17.1, U4.16 (VBUS_EN_SNK)
unnamed: R9.1, U4.18 (VBUS_VS_DISCH)
unnamed: C9.1, U4.21 (VREG_1V2)
unnamed: C8.1, U4.23 (VREG_2V7)
unnamed: C18.1, U5.4 (BP)
VDD: C4.1, C5.1, C7.1, D4.1 (A1), D9.1 (K), F1.2, Q4.1 (S), Q4.2 (S), Q4.3 (S), Q5.3 (C), R27.2, R33.1, U3.2 (EN), U3.3 (IN)

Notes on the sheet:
3.3V LDO REGULATOR
MECHANICAL
Test points connected to GPIO pins
INPUT VOLTAGE SENSE
1.714V output at 24V input
Terminal block DG350-3.5-06P-14-00AH or 2xDG350-3.5-03P-14-00AH
HEATER DRIVE
BUTTONS
STANDBY SENSE INPUT
4.6V output
AMPLIFIER
OLED DISPLAY
TEMPERATURE SENSOR
Shunt resistor 5 mOhm
Fuse: Littelfuse 0154007.DR Alternative: 0451007.MRL (solder directly without fuse holder)
GAIN: 47V/V
Display support pins
SCREW TERMINAL
BUCK VOLTAGE CONVERTER
GAIN: 260V/V
Alternative op-amp: AD8552ARZ (Older gen. slightly worse specs)
Alt. mosfet: AOSP21321
I2C PULL-UP
MCU
Alternative LDO: TLV75733PDBVR
USB TYPE-C POWER DELIVERY
WS2812 RGB status led

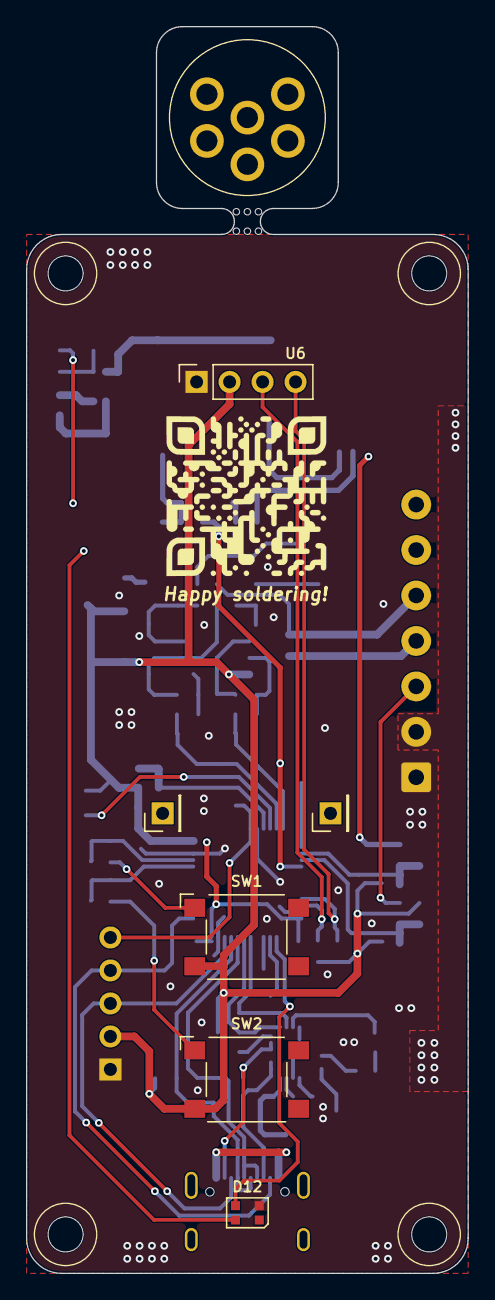
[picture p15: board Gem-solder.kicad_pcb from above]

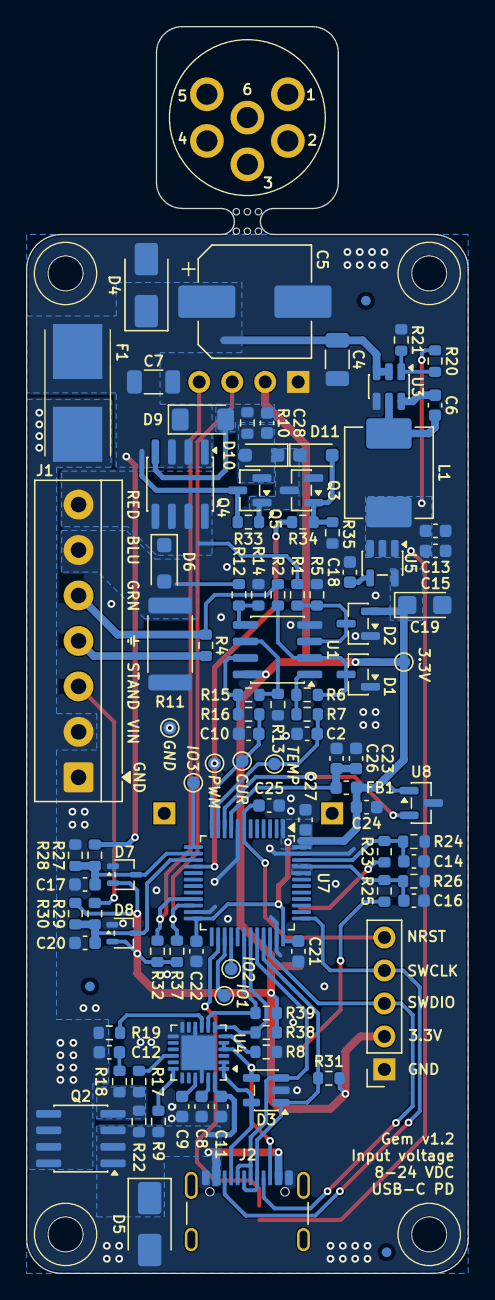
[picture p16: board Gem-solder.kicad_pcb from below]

Board: 2 copper layers, 34.0 x 96.0 mm, 113 parts (101 on the bottom side), 59 nets.

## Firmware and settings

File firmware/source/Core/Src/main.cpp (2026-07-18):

// By Ben V. Brown - V2.0 of the TS100 firmware

/*
 * Main.cpp bootstraps the device and then hands over to FreeRTOS and the threads
 */

#include "main.hpp"
#include "BSP.h"
#include "Settings.h"
#include "cmsis_os.h"
#include "power.hpp"
AccelType DetectedAccelerometerVersion = AccelType::None;
bool      settingsWereReset            = false;
// FreeRTOS variables

osThreadId          GUITaskHandle;
static const size_t GUITaskStackSize = 1024 / 2;
uint32_t            GUITaskBuffer[GUITaskStackSize];
osStaticThreadDef_t GUITaskControlBlock;

osThreadId          PIDTaskHandle;
static const size_t PIDTaskStackSize = 1024 / 2;
uint32_t            PIDTaskBuffer[PIDTaskStackSize];
osStaticThreadDef_t PIDTaskControlBlock;

// osThreadId          MOVTaskHandle;
// static const size_t MOVTaskStackSize = 1024 / 2;
// uint32_t            MOVTaskBuffer[MOVTaskStackSize];
// osStaticThreadDef_t MOVTaskControlBlock;

osThreadId          POWTaskHandle;
static const size_t POWTaskStackSize = 512 / 2;
uint32_t            POWTaskBuffer[POWTaskStackSize];
osStaticThreadDef_t POWTaskControlBlock;

// End FreeRTOS
// Main sets up the hardware then hands over to the FreeRTOS kernel
int main(void) {
  preRToSInit();

  resetWatchdog();
  // Testing for which accelerometer is mounted
  settingsWereReset = loadSettings(); // load the settings from flash

  setTipX10Watts(0); // force tip off

  resetWatchdog();
  /* Create the thread(s) */

  /* definition and creation of PIDTask - Heating control*/
  osThreadStaticDef(PIDTask, startPIDTask, osPriorityRealtime, 0, PIDTaskStackSize, PIDTaskBuffer, &PIDTaskControlBlock);
  PIDTaskHandle = osThreadCreate(osThread(PIDTask), NULL);

  /* definition and creation of POWTask - Power management for QC / PD */
  osThreadStaticDef(POWTask, startPOWTask, osPriorityAboveNormal, 0, POWTaskStackSize, POWTaskBuffer, &POWTaskControlBlock);
  POWTaskHandle = osThreadCreate(osThread(POWTask), NULL);

  // /* definition and creation of MOVTask - Accelerometer management */
  // osThreadStaticDef(MOVTask, startMOVTask, osPriorityNormal, 0, MOVTaskStackSize, MOVTaskBuffer, &MOVTaskControlBlock);
  // MOVTaskHandle = osThreadCreate(osThread(MOVTask), NULL);

  /* definition and creation of GUITask - The OLED control & update*/
  osThreadStaticDef(GUITask, startGUITask, osPriorityBelowNormal, 0, GUITaskStackSize, GUITaskBuffer, &GUITaskControlBlock);
  GUITaskHandle = osThreadCreate(osThread(GUITask), NULL);

  resetWatchdog();

  /* Start scheduler */
  osKernelStart();
  /* We should never get here as control is now taken by the scheduler */
  for (;;) {
  }
}

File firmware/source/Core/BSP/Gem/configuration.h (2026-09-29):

#ifndef CONFIGURATION_H_
#define CONFIGURATION_H_
#include <stdint.h>
/**
 * Configuration.h
 * Define here your default settings
 *
 */

//===========================================================================
//============================= Default Settings ============================
//===========================================================================
/**
 * Default soldering temp is 320.0 C
 * Temperature the iron sleeps at - default 150.0 C
 */

#define SLEEP_TEMP         150 // Default sleep temperature
#define BOOST_TEMP         420 // Default boost temp.
#define BOOST_MODE_ENABLED 1   // 0: Disable 1: Enable

/**
 * Blink the temperature on the cooling screen when its > 50C
 */
#define COOLING_TEMP_BLINK 0 // 0: Disable 1: Enable

/**
 * How many seconds/minutes we wait until going to sleep/shutdown.
 * Values -> SLEEP_TIME * 10; i.e. 5*10 = 50 Seconds!
 */
#define SLEEP_TIME    5  // x10 Seconds
#define SHUTDOWN_TIME 10 // Minutes

/**
 * Auto start off for safety.
 * Possible values are:
 *  0 - none
 *  1 - Soldering Temperature
 *  2 - Sleep Temperature
 *  3 - Sleep Off Temperature
 */
#define AUTO_START_MODE 0 // Default to none

/**
 * Locking Mode
 * When in soldering mode a long press on both keys toggle the lock of the buttons
 * Possible values are:
 *  0 - Desactivated
 *  1 - Lock except boost
 *  2 - Full lock
 */
#define LOCKING_MODE 0 // Default to desactivated for safety

/**
 * OLED Orientation
 *
 */
#define ORIENTATION_MODE     0 // 0: Right 1:Left 2:Automatic - Default Automatic
#define MAX_ORIENTATION_MODE 1 // Up to auto
// 0:Default 1:Reverse - Reverse the plus and minus button assigment for temperature change
#define REVERSE_BUTTON_TEMP_CHANGE 0

/**
 * OLED Brightness
 *
 */
//   #define MIN_BRIGHTNESS     1   // Min OLED brightness selectable
//   #define MAX_BRIGHTNESS     101 // Max OLED brightness selectable
#define MIN_BRIGHTNESS     0   // Min OLED brightness selectable
#define MAX_BRIGHTNESS     100 // Max OLED brightness selectable
#define BRIGHTNESS_STEP    25  // OLED brightness increment
#define DEFAULT_BRIGHTNESS 25  // default OLED brightness

/**
 * Temp change settings
 */
#define TEMP_CHANGE_SHORT_STEP     1  // Default temp change short step +1
#define TEMP_CHANGE_LONG_STEP      10 // Default temp change long step +10
#define TEMP_CHANGE_SHORT_STEP_MAX 50 // Temp change short step MAX value
#define TEMP_CHANGE_LONG_STEP_MAX  90 // Temp change long step MAX value

/* Power pulse for keeping power banks awake*/
#define POWER_PULSE_INCREMENT    1
#define POWER_PULSE_MAX          100 // x10 max watts
#define POWER_PULSE_WAIT_MAX     9   // 9*2.5s = 22.5 seconds
#define POWER_PULSE_DURATION_MAX 9   // 9*250ms = 2.25 seconds

#define POWER_PULSE_DEFAULT          0
#define POWER_PULSE_WAIT_DEFAULT     4 // Default rate of the power pulse: 4*2500 = 10000 ms = 10 s
#define POWER_PULSE_DURATION_DEFAULT 1 // Default duration of the power pulse: 1*250 = 250 ms

/**
 * OLED Orientation Sensitivity on Automatic mode!
 * Motion Sensitivity <0=Off 1=Least Sensitive 9=Most Sensitive>
 */
#define SENSITIVITY 0 // Default 7

/**
 * Detailed soldering screen
 * Detailed idle screen (off for first time users)
 */
#define DETAILED_SOLDERING 0 // 0: Disable 1: Enable - Default 0
#define DETAILED_IDLE      0 // 0: Disable 1: Enable - Default 0

#define THERMAL_RUNAWAY_TIME_SEC 20
#define THERMAL_RUNAWAY_TEMP_C   3

#define CUT_OUT_SETTING          0  // default to no cut-off voltage
#define RECOM_VOL_CELL           33 // Minimum voltage per cell (Recommended 3.3V (33))
#define TEMPERATURE_INF          0  // default to 0
#define DESCRIPTION_SCROLL_SPEED 0  // 0: Slow 1: Fast - default to slow
#define ANIMATION_LOOP           1  // 0: off 1: on
#define ANIMATION_SPEED          settingOffSpeed_t::MEDIUM

#define ADC_MAX_READING (4096 * 8) // Maximum reading of the adc
#define ADC_VDD_MV      3300       // ADC max reading millivolts

// Deriving the Voltage div:
// Vin_max = (3.3*(r1+r2))/(r2)
// vdiv = (32768*4)/(vin_max*10)

#if defined(MODEL_Gem) > 1
#error "Multiple models defined!"
#elif defined(MODEL_Gem) == 0
#error "No model defined!"
#endif
#define NEEDS_VBUS_PROBE 0

// Power delivery.
// There're a lot of PD logic tied to FUSB when POW_PD 1
// so a new define POW_PD_STUSB4500 was introduced for Gem
#define POW_PD_STUSB4500 1
#define USB_PD_I2CBB2    1  // PD controller is on the I2C bus 2
#define USB_PD_VMAX      20 // Max voltage to negotiate with PD source
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

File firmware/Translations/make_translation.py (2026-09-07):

#!/usr/bin/env python3

import argparse
import functools
import json
import hashlib
import logging
import os
import pickle
import re
import subprocess
import sys
import time
from pathlib import Path
from typing import Dict, List, Optional, TextIO, Tuple, Union
from dataclasses import dataclass

from bdflib import reader as bdfreader
from bdflib.model import Font, Glyph

import font_tables
import brieflz
import objcopy

logging.basicConfig(stream=sys.stdout, level=logging.DEBUG)

HERE = Path(__file__).resolve().parent


@functools.lru_cache(maxsize=None)
def cjk_font() -> Font:
    with open(os.path.join(HERE, "wqy-bitmapsong/wenquanyi_9pt.bdf"), "rb") as f:
        return bdfreader.read_bdf(f)


# Loading a single JSON file
def load_json(filename: str) -> dict:
    with open(filename) as f:
        return json.loads(f.read())


def get_language_unqiue_id(language_ascii_name: str):
    """
    Given a language code, it will return a unique (enough) uint16_t id code
    When we have a collision here we can tweak this, but language list should be fairly stable from now on
    """
    return (
        int(hashlib.sha1(language_ascii_name.encode("utf-8")).hexdigest(), 16) % 0xFFFF
    )


def read_translation(json_root: Union[str, Path], lang_code: str) -> dict:
    filename = f"translation_{lang_code}.json"

    file_with_path = os.path.join(json_root, filename)

    try:
        lang = load_json(file_with_path)
    except json.decoder.JSONDecodeError as e:
        logging.error(f"Failed to decode {filename}")
        logging.exception(str(e))
        sys.exit(2)

    validate_langcode_matches_content(filename, lang)

    return lang


def filter_translation(lang: dict, defs: dict, macros: frozenset):
    def check_excluded(record):
        if "include" in record and not any(m in macros for m in record["include"]):
            return True

        if "exclude" in record and any(m in macros for m in record["exclude"]):
            return True

        return False

    for category in ("menuOptions", "menuGroups", "menuValues"):
        for _, record in enumerate(defs[category]):
            if check_excluded(record):
                lang[category][record["id"]]["displayText"] = ""
                lang[category][record["id"]]["description"] = ""

    for _, record in enumerate(defs["messagesWarn"]):
        if check_excluded(record):
            lang["messagesWarn"][record["id"]]["message"] = ""

    return lang


def validate_langcode_matches_content(filename: str, content: dict) -> None:
    # Extract lang code from file name
    lang_code = filename[12:-5].upper()
    # ...and the one specified in the JSON file...
    try:
        lang_code_from_json = content["languageCode"]
    except KeyError:
        lang_code_from_json = "(missing)"

    # ...cause they should be the same!
    if lang_code != lang_code_from_json:
        raise ValueError(
            f"Invalid languageCode {lang_code_from_json} in file {filename}"
        )


def write_start(f: TextIO):
    f.write(
        "// WARNING: THIS FILE WAS AUTO GENERATED BY make_translation.py. PLEASE DO NOT EDIT.\n"
    )
    f.write("\n")
    f.write('#include "Translation.h"\n')
    # configuration.h defines OLED_128x32, which selects the larger font tables
    f.write('#include "configuration.h"\n')


def get_constants() -> List[Tuple[str, str]]:
    # Extra constants that are used in the firmware that are shared across all languages
    return [
        ("LargeSymbolPlus", "+"),
        ("SmallSymbolPlus", "+"),
        ("LargeSymbolMinus", "-"),
        ("SmallSymbolMinus", "-"),
        ("LargeSymbolSpace", " "),
        ("SmallSymbolSpace", " "),
        ("LargeSymbolDot", "."),
        ("SmallSymbolDot", "."),
        ("SmallSymbolSlash", "/"),
        ("SmallSymbolColon", ":"),
        ("LargeSymbolDegC", "C"),
        ("SmallSymbolDegC", "C"),
        ("LargeSymbolDegF", "F"),
        ("SmallSymbolDegF", "F"),
        ("LargeSymbolMinutes", "m"),
        ("SmallSymbolMinutes", "m"),
        ("LargeSymbolSeconds", "s"),
        ("SmallSymbolSeconds", "s"),
        ("LargeSymbolWatts", "W"),
        ("SmallSymbolWatts", "W"),
        ("LargeSymbolVolts", "V"),
        ("SmallSymbolVolts", "V"),
        ("SmallSymbolAmps", "A"),
        ("LargeSymbolDC", "DC"),
        ("LargeSymbolCellCount", "S"),
        ("SmallSymbolVersionNumber", read_version()),
        ("SmallSymbolPDDebug", "PD Debug"),
        ("SmallSymbolState", "State"),
        ("SmallSymbolNoVBus", "No VBus"),
        ("SmallSymbolVBus", "VBus"),
        ("LargeSymbolSleep", "Zzz "),
    ]


def get_debug_menu() -> List[str]:
    return [
        time.strftime(
            "%Y%m%d %H%M%S",
            time.gmtime(int(os.environ.get("SOURCE_DATE_EPOCH", time.time()))),
        ),
        "ID ",
        "ACC   ",
        "PWR   ",
        "Vin        ",
        "Tip C  ",
        "Han C  ",
        "Max C  ",
        "UpTime ",
        "Move   ",
        "Tip Res",
        "Tip R  ",
        "Tip O  ",
        "HW G   ",
        "HW M   ",
        "HW P   ",
        "PSWL   ",
        "Hall   ",
    ]


def get_accel_names_list() -> List[str]:
    return [
        "Scanning",
        "None",
        "MMA8652FC",
        "LIS2DH12",
        "BMA223",
        "MSA301",
        "SC7A20",
        "GPIO",
        "LIS2 CLONE",
    ]


def get_power_source_list() -> List[str]:
    return [
        "DC",
        "QC",
        "PV:PDwVBus",
        "PD:No VBus",
    ]


# On 128x32 panels the scrolling menu descriptions are drawn with the small
# (Terminus 8x16) font instead of the large one, so they must be ranked and
# encoded against the small font. Set from the build macros in main().
DESCRIPTIONS_USE_SMALL_FONT = False


def test_is_small_font(msg: str) -> bool:
    return "\n" in msg and msg[0] != "\n"


@functools.lru_cache(maxsize=None)
def small_font_chars() -> frozenset:
    """The set of characters that have a glyph in the small (6x8) font.

    The small font only covers ASCII/Latin-Extended/Cyrillic/Greek; CJK glyphs
    are rendered into the large (12x16) font exclusively. Used to decide whether
    a message can be drawn in the small font at all.
    """
    chars: set = set()
    for font in font_tables.ALL_PRE_RENDERED_FONTS:
        _, font06 = font_tables.get_font_maps_for_name(font)
        chars.update(font06.keys())
    return frozenset(chars)
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

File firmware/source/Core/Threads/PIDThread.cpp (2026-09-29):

/*
 * PIDThread.cpp
 *
 *  Created on: 29 May 2020
 *      Author: Ralim
 */

#include "BSP.h"
#include "FreeRTOS.h"
#include "Settings.h"
#include "TipThermoModel.h"
#include "cmsis_os.h"
#include "configuration.h"
#include "expMovingAverage.h"
#include "history.hpp"
#include "main.hpp"
#include "power.hpp"
#include "task.h"

#ifdef POW_PD
#if POW_PD == 1
#include "USBPD.h"
#endif
#endif

#ifdef POW_PD_STUSB4500
#include "STUSB4500.hpp"
#endif

static TickType_t          powerPulseWaitUnit          = 25 * TICKS_100MS;      // 2.5 s
static TickType_t          powerPulseDurationUnit      = (5 * TICKS_100MS) / 2; // 250 ms
TaskHandle_t               pidTaskNotification         = NULL;
volatile TemperatureType_t currentTempTargetDegC       = 0; // Current temperature target in C
int32_t                    powerSupplyWattageLimit     = 0;
uint8_t                    heaterThermalRunawayCounter = 0;

static int32_t getPIDResultX10Watts(TemperatureType_t set_point, TemperatureType_t current_value);
static void    detectThermalRunaway(const TemperatureType_t currentTipTempInC, const uint32_t x10WattsOut);
static void    setOutputx10WattsViaFilters(int32_t x10Watts);
static int32_t getX10WattageLimits();

#ifdef PID_DEBUG
volatile int32_t PIDDebugResults[3] = {0, 0, 0};
#endif

/* StartPIDTask function */
void startPIDTask(void const *argument __unused) {
  /*
   * We take the current tip temperature & evaluate the next step for the tip
   * control PWM.
   */
  setTipX10Watts(0); // disable the output at startup

  currentTempTargetDegC = 0; // Force start with no output (off). If in sleep / soldering this will
                             // be over-ridden rapidly

  pidTaskNotification = xTaskGetCurrentTaskHandle();

  TemperatureType_t PIDTempTarget = 0;
  // Pre-seed the adc filters
  for (int i = 0; i < 32; i++) {
    ulTaskNotifyTake(pdTRUE, 5);
    TipThermoModel::getTipInC(true);
    getInputVoltageX10(getSettingValue(SettingsOptions::VoltageDiv), 1);
  }

  while (preStartChecks() == 0) {
    resetWatchdog();
    ulTaskNotifyTake(pdTRUE, 2000);
  }
// Wait for PD if its in the middle of negotiation
#ifdef POW_PD
#if POW_PD == 1
  // This is an FUSB based PD capable device
  // Wait up to 3 seconds for USB-PD to settle
  while (USBPowerDelivery::negotiationInProgress() && xTaskGetTickCount() < (TICKS_SECOND * 3)) {
    resetWatchdog();
    ulTaskNotifyTake(pdTRUE, TICKS_100MS);
  }
#endif
#endif
#ifdef POW_PD_STUSB4500
  while (!STUSB4500::has_negotiated() && xTaskGetTickCount() < TICKS_SECOND * 2) {
    resetWatchdog();
    ulTaskNotifyTake(pdTRUE, TICKS_100MS);
  }
#endif

  int32_t    x10WattsOut             = 0;
  TickType_t lastThermalRunawayDecay = xTaskGetTickCount();

  for (;;) {
    x10WattsOut = 0;
    // This is a call to block this thread until the ADC does its samples
    if (ulTaskNotifyTake(pdTRUE, TICKS_SECOND * 2)) {
      // Do the reading here to keep the temp calculations churning along
      TemperatureType_t currentTipTempInC = TipThermoModel::getTipInC(true);

      PIDTempTarget = currentTempTargetDegC;
      if (PIDTempTarget > 0) {
        // Cap the max set point to 450C
        if (PIDTempTarget > 450) {
          // Maximum allowed output
          PIDTempTarget = 450;
        }
        // Safety check that not aiming higher than current tip can measure
        if (PIDTempTarget > TipThermoModel::getTipMaxInC()) {
          PIDTempTarget = TipThermoModel::getTipMaxInC();
        }

        x10WattsOut = getPIDResultX10Watts(PIDTempTarget, currentTipTempInC);
        detectThermalRunaway(currentTipTempInC, x10WattsOut);
      } else {
        detectThermalRunaway(currentTipTempInC, 0);
      }
      setOutputx10WattsViaFilters(x10WattsOut);
    } else {
      // ADC interrupt timeout
      setTipPWM(0, false);
    }
#ifdef DEBUG_UART_OUTPUT
    log_system_state(x10WattsOut);
#endif
    if (xTaskGetTickCount() - lastThermalRunawayDecay > TICKS_SECOND) {
      lastThermalRunawayDecay = xTaskGetTickCount();
      if (heaterThermalRunawayCounter > 0) {
        heaterThermalRunawayCounter--;
      }
    }
  }
}

#ifdef TIP_CONTROL_PID
template <class T, T Kp, T Ki, T Kd> struct PID {
  T previous_error_term;
  T integration_running_sum;
  // Filter Kd result to reduce power swings caused by temperature measurement noise amplification
  expMovingAverage<T, 48> kd_result_filter = {0};

  T update(const T set_point, const T new_reading, const TickType_t interval_ms, const T max_output) {
    const T target_delta = set_point - new_reading;

    // Proportional term
    const T kp_result = Kp * target_delta;
    // Integral probe before anti-windup decision
    T ki_probe = integration_running_sum / 100;
    // Derivative term
    T derivative        = (target_delta - previous_error_term);
    T kd_result_instant = ((Kd * derivative) / (T)(interval_ms));
    kd_result_filter.update(kd_result_instant);
    T kd_result = kd_result_filter.average();

    T output_probe = kp_result + ki_probe + kd_result;

    // Integral term as we use mixed sampling rates, we cant assume a constant sample interval
    // Thus we multiply this out by the interval time to ~= dv/dt
    // Then the shift by 1000 is ms -> Seconds.
    // In order to prevent windup we don't accumulate integrator when the output is already saturated
    bool is_saturated = (output_probe >= max_output && target_delta > 0) || (output_probe <= 0 && target_delta < 0);
    if (!is_saturated) {
      integration_running_sum += (target_delta * (T)interval_ms * Ki) / 1000;
    }

    // Calculate the integral term, we use a shift 100 to get precision in integral as we often need small amounts
    T ki_result = integration_running_sum / 100;

    // Summation of the outputs
    T output = kp_result + ki_result + kd_result;

#ifdef PID_DEBUG
    PIDDebugResults[0] = kp_result;
    PIDDebugResults[1] = ki_result;
    PIDDebugResults[2] = kd_result;
#endif

    // Restrict to max / 0
    if (output > max_output) {
      output = max_output;
    } else if (output < 0) {
      output = 0;
    }

    // Save target_delta to previous target_delta
    previous_error_term = target_delta;

    return output;
  }
};
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

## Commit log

2026-07-18 Add firmware source files
    [configuration.h]
2026-07-19 Change tip measurement PWM duty
    [configuration.h]
2026-07-20 Use callback scoped variable to avoid pendingPWM overwrite
    [BSP.cpp]
2026-07-23 Disable current sampling in CJC calibration mode
2026-07-23 Show sleep settings which were hidden when accelerometer sensivity disabled
2026-07-24 Don't force higher PWM duty for current sampling in soldering mode
2026-07-24 Adjust buck converter output voltage
    [Gem-solder.kicad_sch]
2026-07-25 Update symbol fields table with appropriate part numbers
    [Gem-solder.kicad_sch]
2026-07-25 Update OLED display part number fields
    [Gem-solder.kicad_sch]
2026-07-25 Replace commas in symbol fields to fix CSV BOM export
    [Gem-solder.kicad_sch]
2026-07-26 Update PCB from schematics
    [Gem-solder.kicad_pcb]
2026-07-27 Update I2C pins accordingly to the new PCB layout
2026-07-27 Update heater driver and vbus_en_snk resistors
    [Gem-solder.kicad_sch]
2026-07-27 Configure I2C soft bus 2 for PD controller
    [configuration.h]
2026-07-27 Reduce tip measurement PWM duty
    [configuration.h]
2026-07-29 Change I2C start sequence
2026-07-30 Implement PD driver for STUSB4500
    [configuration.h]
2026-07-30 Fix power source display in debug menu
2026-07-30 Update negotiation check
    [configuration.h]
2026-07-30 Add delay before first current sampling
2026-07-30 Fix soldering screen startup behaviour
    [BSP.cpp]
2026-07-30 PID thread wait for PD negotiation
2026-07-30 Increase current sampling startup delay
2026-07-30 Prevent PID thread from starting heating if PD negotiation not done yet
    [PIDThread.cpp, STUSB4500.cpp]
2026-07-31 Implement PD debug menu
    [configuration.h]
2026-07-31 Update enclosure
    [Gem_Solder_Enclosure.FCStd]
2026-07-31 Improve heater drive efficiency
    [Gem-solder.kicad_sch]
2026-07-31 Fine tune tip profiles
    [configuration.h]
2026-08-01 Draw heat symbol on the detailed screen
2026-08-01 Adjust min temperature
    [configuration.h]
2026-08-01 Add power rating to the tip profile and adjust max power config
    [configuration.h]
2026-08-02 Add replacement LDO note
    [Gem-solder.kicad_sch]
2026-08-03 Change max wattage
    [configuration.h]
2026-08-03 Change current sampling startup delay
2026-08-03 Improve tip resistance measurement precision
    [configuration.h]
2026-08-03 Increase inertia. With improved tip resistance measurement acuracy it tends to overshoot
2026-08-04 Add WS2812 RGB LED feature
    [configuration.h]
2026-08-04 Add status LED state for sleeping mode
2026-08-06 Sample stand sense pin using ADC
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2026-08-06 Change power limit
    [configuration.h]
2026-08-06 Fix heat symbol rendering in L screen orientation
2026-08-06 Rewrite soldering screen drawing to have a consistent elements order for both L and R display orientations
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2026-08-07 Add status LED hysteresis between cooling and standby transitions
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2026-08-08 Update schematics
    [Gem-solder.kicad_sch]
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2026-08-10 Limit number of current sampling pulses while idling
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2026-08-14 Schematics update: new mosfet driver topology for fast switching; added WS2812 RGB LED
    [Gem-solder.kicad_sch]
2026-08-14 Increase PWM frequency to 20 khz and use fast PWM only
    [configuration.h]
2026-08-15 Change current measurement approach: 2 samples per second with a moving average filter
    [configuration.h]
2026-08-15 Force current sampling even in soldering mode with a single high PWM duty pulse
2026-08-19 PCB updates: mosfet driver, WS2812 LED, USB data lines
    [Gem-solder.kicad_pcb, Gem-solder.kicad_sch]
2026-08-20 Add 3D model for WS2812 footprint
    [Gem-solder.kicad_pcb, Gem-solder.kicad_sch, WS2812-2020.STEP]
2026-08-22 PCB: add ground polygon via
    [Gem-solder.kicad_pcb]
2026-08-22 Cleanup unused config options
    [configuration.h]
2026-08-23 Add power supply wattage limit to debug menu
2026-08-24 Refactor PD negotiation to fix unknown wattage limit
    [STUSB4500.cpp]
2026-08-28 Use PID instead of self-decay integrator for better temperature stability
    [configuration.h]
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2026-08-31 Adjust PID parameters for more stable idling near setpoint
    [configuration.h]
2026-08-31 Add should device shutdown check based on stand sense feature
2026-08-31 Add NO_ACCEL guard for should device sleep check
2026-09-03 Change D term scale and tune
    [configuration.h]
2026-09-03 Change status LED color for cooling still hot status
2026-09-04 Adjust calibration offset
    [configuration.h]
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2026-09-06 Update schematics symbols fields
    [Gem-solder.kicad_sch]
2026-09-07 Flip OLED orientation and buttons
    [configuration.h]
2026-09-07 Cyan status LED color for cooling still hot status
2026-09-07 Change PD debug menu activation button and cleanup config
    [configuration.h]
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2026-09-15 Implement PID Ki term anti-windup
    [configuration.h]
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2026-09-18 Change WS2812 LED pin for new board revision
2026-09-19 Add USB D+ pull-up resistor
    [Gem-solder.kicad_pcb, Gem-solder.kicad_sch]
2026-09-19 Enter PD debug menu from system debug
    [configuration.h]
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2026-09-20 Avoid float math and clamp tip resistance calculated result
    [BSP.cpp]
2026-09-21 Add status LED brightness setting
    [configuration.h]
2026-09-23 Move USBDP pull-up to MCU section. Add thermal gaps to WS2812 GND pin for easier handsoldering
    [Gem-solder.kicad_pcb, Gem-solder.kicad_sch]
2026-09-23 Slightly brighter green for standby status LED color
2026-09-23 Add PID debug feature
    [configuration.h]
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2026-09-25 Fix build script output truncation for enclosure build stage
2026-09-26 Update enclosure design
    [Gem_Solder_Enclosure.FCStd]
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2026-09-27 Remove stale info
    [configuration.h]
2026-09-28 README work in progress
    [Gem-solder.kicad_sch]
2026-09-29 Change BOM file format
    [Gem Solder BOM.xlsx]
2026-09-30 Update schematic symbol fields
    [Gem-solder.kicad_sch]
2026-09-30 Remove unrelated comment
    [Gem-solder.kicad_sch]
2026-09-30 Update BOM
    [Gem Solder BOM.xlsx]
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2026-10-21 Refactor: remove accelerometer and hall sensor support
    The Gem board has neither an accelerometer nor a hall-effect sensor, so
    remove the inherited support end to end.
    - delete accelerometer and Si7210 drivers, MOV task, and motion sleep helpers
    - drop accelerometer/hall settings, menus, debug items, and translations
    - remove automatic display rotation
    - blank the OLED after 60 s without button input when the tip is below 50 C
    - bump SETTINGSVERSION to 0x55AC to reset incompatible saved settings
2026-10-21 Fix unreachable tip short current detection
2026-10-21 Draw heat symbol relative to wattage limit rather than max PWM
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2026-10-21 Fix heat symbol unreachable full scale
